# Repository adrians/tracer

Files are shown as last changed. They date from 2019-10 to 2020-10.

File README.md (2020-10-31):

# Electronic tracer

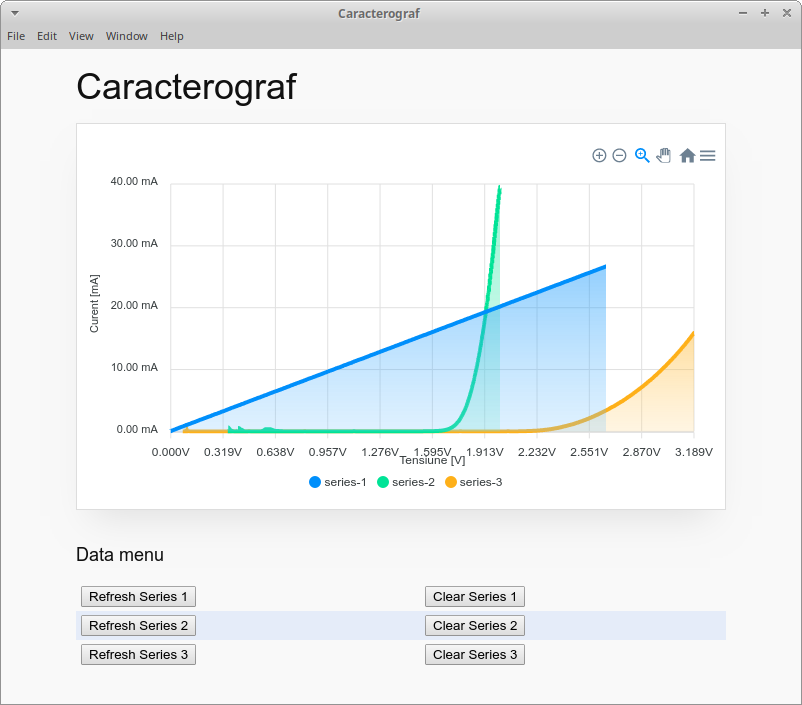
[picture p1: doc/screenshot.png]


## The "driver-v1" folder

* Use it for physical tracer board, version 1.
* Prerequisites: `libudev1` and `g++` installed (`sudo apt-get install libudev1 build-essential`).
* Driver based on Kerry Wong's library (<https://github.com/kerrydwong/MCP2210-Library>).
* To build the driver-application, run `cd driver-v1; make`. It will generate the `tracer` binary, which should be run as root (or with the `setuid` bit set).

## The "driver-mock" folder

* Use it for local testing, without a tracer board. It's a dummy data source.
* Prerequisites: `g++` installed.
* To build it, run `cd driver-mock; make`. It will generate the `tracer` binary.

## The "frontend" directory

* Frontend done using electron.js and apex charts.
* It uses `npm`.
* To build, run `npm install`.
* To run, copy the `tracer` binary (from either `driver-v1` or `driver-mock` directories), and then run `npm start`.
* Tested with node 14.x.

The `driver-v1` requires setuid permissions. See the snippet below.

```bash
cd frontend
cp ../driver-v1/tracer .
sudo chown root tracer
sudo chmod +s tracer
npm start
```

## The "board" directory

* Contains the kicad project used for manufacturing the first iteration of the board.

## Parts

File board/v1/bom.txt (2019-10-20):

22pF, 2buc, C1 C2,      https://ro.farnell.com/vishay/k220j15c0gf53l2/cap-22pf-50v-5-c0g-np0/dp/1141760
10nF, 2buc, C7 C8,      https://ro.farnell.com/multicomp/mc0805y103m500a5-08mm/cap-0-01-f-50v-20-y5v/dp/2309024
1uF, 1buc, C5,          https://ro.farnell.com/multicomp/mcnp35v105m5x11/cap-1-f-35v-20/dp/1236666
2.2uF, 3buc, C3 C4 C6,  https://ro.farnell.com/multicomp/mcksk100m2r2d11s/cap-2-2-f-100v-20/dp/2610808
10uF, 1buc, C9,         https://ro.farnell.com/multicomp/mcgpr16v106m5x11/cap-10-f-16v-20/dp/9451056

led5mm, 1buc, D1,       https://ro.farnell.com/multicomp/mcl053pd/led-5mm-36-hi-red/dp/1581136

100R, 2buc, R1 R2,      https://ro.farnell.com/multicomp/mf25-100r/res-100r-1-250mw-axial-metal-film/dp/9341099
1k, 2buc, R3 R4,        https://ro.farnell.com/multicomp/mcf-0-25w-1k/res-1k-5-250mw-axial-carbon-film/dp/9339051

12MHz xtal, Y1, 1buc,   https://ro.farnell.com/qantek-technology-corporation/qcl12-0000f18b23b/crystal-12mhz-18pf-hc-49us/dp/2508453

terminal 2way 5.08pitch, 2buc, J1 J3,        https://ro.farnell.com/wago/235-402-331-000/terminal-block-wire-to-brd-2pos/dp/1891596

USB B, J2, 1buc,    https://ro.farnell.com/multicomp/usb-b-s-ra/usb-2-0-type-b-receptacle-th/dp/2112373

NPN, Q1, 1buc,      https://ro.farnell.com/stmicroelectronics/tip50/transistor-npn-to-220/dp/1467926
7805, U5, 1buc,     https://ro.farnell.com/stmicroelectronics/l7805cv/ic-v-reg-5-0v-7805-to-220-3/dp/9756078

MCP2210 SOIC, U4, 1buc,     https://ro.farnell.com/microchip/mcp2210-i-so/ic-usb-to-spi-converter-20soic/dp/2078574
MCP4921, U1, 1buc,  https://ro.farnell.com/microchip/mcp4921-e-p/12bit-dac-singl-spi-i-f-mcp4921/dp/1332112
MCP3204, U2, 1buc,  https://ro.farnell.com/microchip/mcp3204-ci-p/ic-12bit-adc-3204-dip14/dp/9758593
MCP6002, U3, 1buc,  https://ro.farnell.com/microchip/mcp6002-i-p/ic-op-amp-1-8v-1mhz-dual-pdip8/dp/1292245
MAX6241, U6, 1buc,  https://ro.farnell.com/maxim-integrated-products/max6241bcpa/voltage-ref-series-4-096v-dip/dp/2511209

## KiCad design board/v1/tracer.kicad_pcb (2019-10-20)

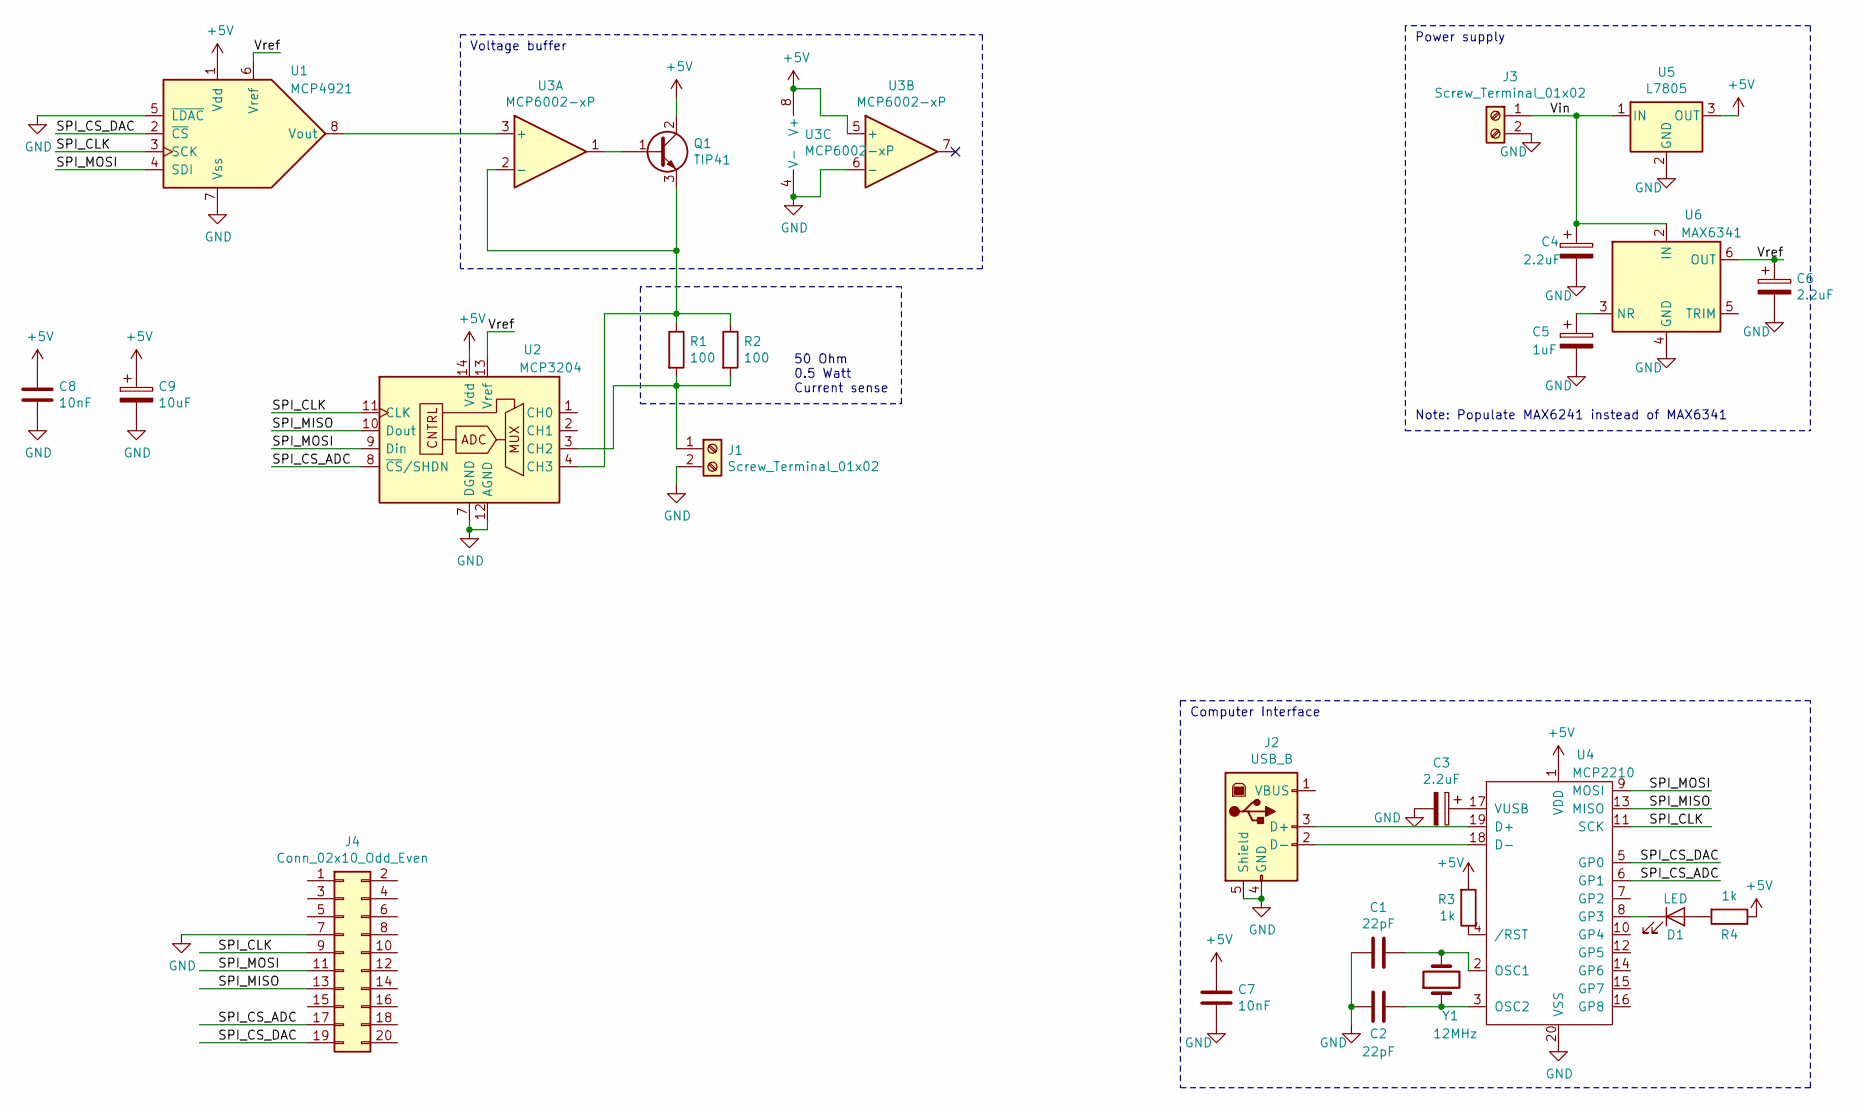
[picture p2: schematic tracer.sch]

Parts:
C1, C2: 22pF; C_Disc_D3.0mm_W1.6mm_P2.50mm
C3, C4, C6: 2.2uF; CP_Radial_D4.0mm_P2.00mm
C5: 1uF; CP_Radial_D4.0mm_P2.00mm
C7, C8: 10nF; C_Disc_D3.0mm_W1.6mm_P2.50mm
C9: 10uF; CP_Radial_D4.0mm_P1.50mm
D1: LED; LED_D5.0mm
J1, J3: Screw_Terminal_01x02; TerminalBlock_Phoenix_MKDS-3-2-5.08_1x02_P5.08mm_Horizontal
J2: USB_B; USB_B_OST_USB-B1HSxx_Horizontal
J4: Conn_02x10_Odd_Even; PinHeader_2x10_P2.54mm_Vertical
Q1: TIP41; TO-220-3_Horizontal_TabDown
R1, R2: 100; R_Axial_DIN0207_L6.3mm_D2.5mm_P7.62mm_Horizontal
R3, R4: 1k; R_Axial_DIN0207_L6.3mm_D2.5mm_P7.62mm_Horizontal
U1: MCP4921; DIP-8_W7.62mm
U2: MCP3204; DIP-14_W7.62mm
U3: MCP6002-xP; DIP-8_W7.62mm
U4: MCP2210; SOIC-20W_7.5x12.8mm_P1.27mm
U5: L7805; TO-220-3_Horizontal_TabDown
U6: MAX6341; DIP-8_W7.62mm
Y1: 12MHz; Crystal_HC50_Vertical

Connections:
+5V: C7.1, C8.1, C9.1, Q1.2 (C), R3.2, R4.1, U1.1 (Vdd), U2.14 (Vdd), U3.5 (+), U3.8 (V+), U4.1 (VDD), U5.3 (OUT)
/SPI_CLK: J4.9, U1.3 (SCK), U2.11 (CLK), U4.11 (SCK)
/SPI_CS_ADC: J4.17, U2.8 (~CS~/SHDN), U4.6 (GP1)
/SPI_CS_DAC: J4.19, U1.2 (~CS), U4.5 (GP0)
/SPI_MISO: J4.13, U2.10 (Dout), U4.13 (MISO)
/SPI_MOSI: J4.11, U1.4 (SDI), U2.9 (Din), U4.9 (MOSI)
/Vin: C4.1, J3.1, U5.1 (IN), U6.2 (IN)
/Vref: C6.1, U1.6 (Vref), U2.13 (Vref), U6.6 (OUT)
GND: C1.2, C2.1, C3.2, C4.2, C5.2, C6.2, C7.2, C8.2, C9.2, J1.2, J2.4 (GND), J2.5 (Shield), J3.2, J4.7, U1.5 (~LDAC), U1.7 (Vss), U2.7 (DGND), U2.12 (AGND), U3.4 (V-), U3.6 (-), U4.20 (VSS), U5.2 (GND), U6.4 (GND)
unnamed: C1.1, U4.2 (OSC1), Y1.2
unnamed: C2.2, U4.3 (OSC2), Y1.1
unnamed: C3.1, U4.17 (VUSB)
unnamed: C5.1, U6.3 (NR)
unnamed: D1.1 (K), U4.8 (GP3)
unnamed: D1.2 (A), R4.2
unnamed: J1.1, R1.2, R2.2, U2.3 (CH2)
unnamed: J2.2 (D-), U4.18 (D-)
unnamed: J2.3 (D+), U4.19 (D+)
unnamed: Q1.1 (B), U3.1
unnamed: Q1.3 (E), R1.1, R2.1, U2.4 (CH3), U3.2 (-)
unnamed: R3.1, U4.4 (/RST)
unnamed: U1.8 (Vout), U3.3 (+)

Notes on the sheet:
Power supply
Note: Populate MAX6241 instead of MAX6341
Computer Interface
50 Ohm 0.5 Watt Current sense
Voltage buffer

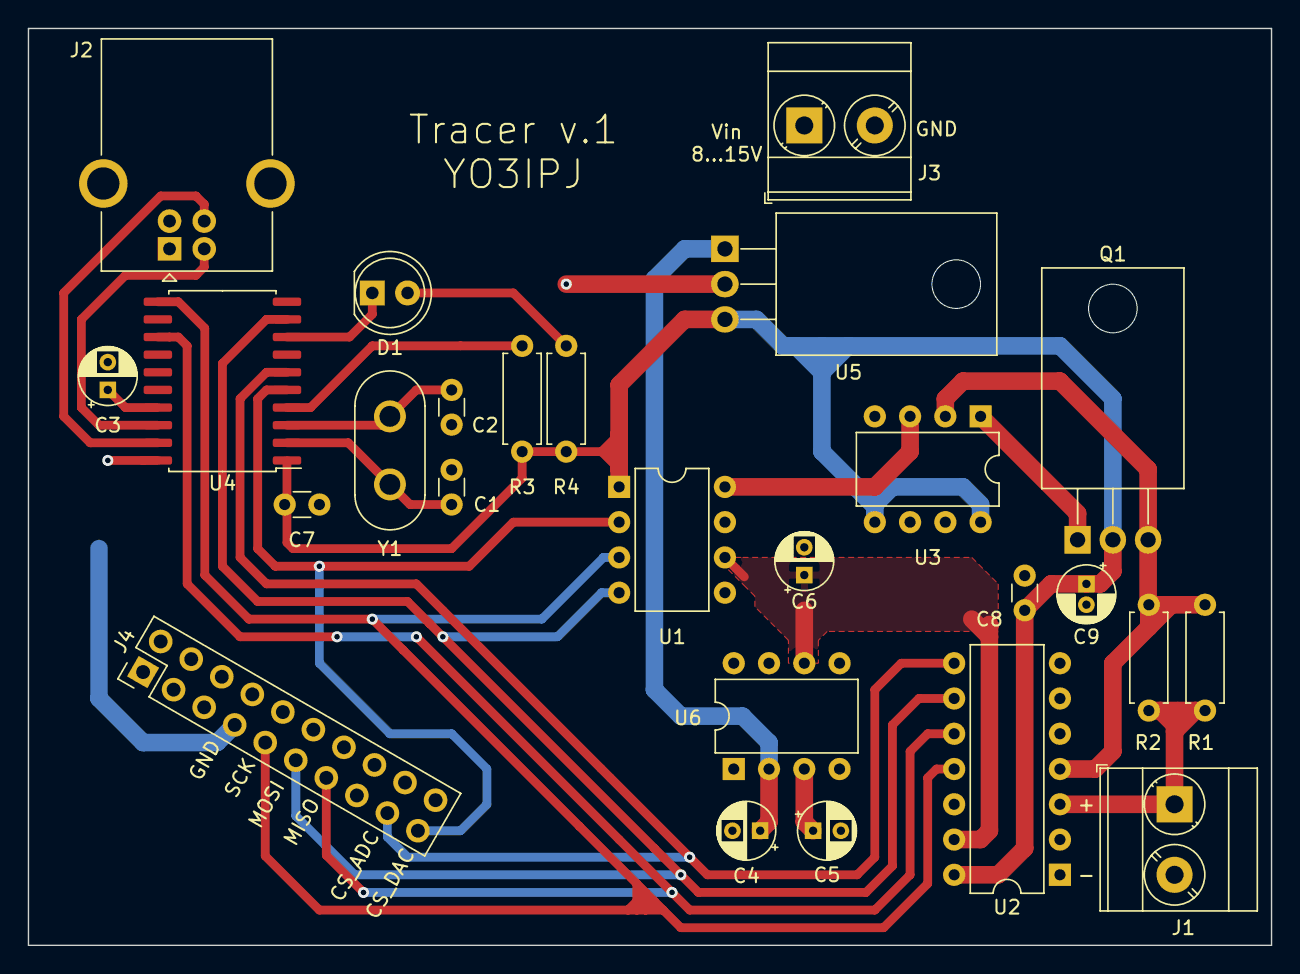
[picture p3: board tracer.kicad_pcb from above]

Board: 2 copper layers, 89.5 x 66.0 mm, 26 parts (0 on the bottom side), 22 nets.

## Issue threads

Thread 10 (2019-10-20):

Next-gen board

adrians, 2019-10-20:
Must-have:
[ ] mounting holes
[ ] input voltage protection
[ ] reverse supply voltage protection
[ ] cheaper voltage reference
[ ] DUT discharge resistor (v1 can "source" current but cannot lower the DUT voltage by itself)

Nice-to-have:
[ ] on-board SPI chip - provide fast sampling and buffer data to RAM - allow RC characteristics to be plotted
[ ] transistor-tracer (add another channel)

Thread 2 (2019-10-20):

DEB build

adrians, 2019-10-20:
Currently, the application is delivered as a "zip" file which is uncompressed manually. This procedure does not preserve the "setuid" bit).

Packaging it as a "deb" would solve a few problems (setting the "setuid" bit, adding the application in path, adding it to the GUI menus).

Needed: script that makes a build and generates the "deb" package.

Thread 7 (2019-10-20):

Driver error handling

adrians, 2019-10-20:
Implement better error handling.

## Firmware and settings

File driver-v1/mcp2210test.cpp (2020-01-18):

/**
 *    Copyright 2012, Kerry D. Wong
 * 
 *      http://www.kerrywong.com
 *
 *  Licensed under the Apache License, Version 2.0 (the "License");
 *  you may not use this file except in compliance with the License.
 *  You may obtain a copy of the License at
 *
 *      http://www.apache.org/licenses/LICENSE-2.0
 *
 *  Unless required by applicable law or agreed to in writing, software
 *  distributed under the License is distributed on an "AS IS" BASIS,
 *  WITHOUT WARRANTIES OR CONDITIONS OF ANY KIND, either express or implied.
 *  See the License for the specific language governing permissions and
 *  limitations under the License.
 */

#include "mcp2210.h"

using namespace std;

static SPITransferSettingsDef def;

void initTracer(hid_device* handle) {
    ChipSettingsDef chipDef;

    //set GPIO pins to be CS
    chipDef = GetChipSettings(handle);

    for (int i = 0; i < 9; i++) {
        if (i == 3) {
        	chipDef.GP[i].PinDesignation = GP_PIN_DESIGNATION_DEDICATED;
        	chipDef.GP[i].GPIODirection = GPIO_DIRECTION_OUTPUT;
        	chipDef.GP[i].GPIOOutput = 1;
        } else {
		chipDef.GP[i].PinDesignation = GP_PIN_DESIGNATION_CS;
        	chipDef.GP[i].GPIODirection = GPIO_DIRECTION_OUTPUT;
        	chipDef.GP[i].GPIOOutput = 1;
	}
    }

    int r = SetChipSettings(handle, chipDef);
    if (r != 0) {
        printf("Error setting SPI parameters.\n");
        return;
    }
    def = GetSPITransferSettings(handle);
}

void SetMCP4921(hid_device* handle, uint16_t input) {
    //chip select is GP0
    def.ActiveChipSelectValue = 0xfffe;
    def.IdleChipSelectValue = 0xffff;
    def.BitRate = 50000l;
    def.BytesPerSPITransfer = 2;

    int r = SetSPITransferSettings(handle, def);

    if (r != 0) {
        printf("Error setting SPI parameters.\n");
        return;
    }
    
    byte spiCmdBuffer[2];
    spiCmdBuffer[0] = (0x30) | ((input >> 8) & 0x0F);
    spiCmdBuffer[1] = (input & 0xFF);
    SPIDataTransferStatusDef def1 = SPISendReceive(handle, spiCmdBuffer, 2);
}

uint16_t GetMCP3204(hid_device* handle, uint8_t channel) {
    //chip select is GP0
    def.ActiveChipSelectValue = 0xfffd;
    def.IdleChipSelectValue = 0xffff;
    def.BitRate = 50000l;
    def.BytesPerSPITransfer = 3;

    int r = SetSPITransferSettings(handle, def);

    if (r != 0) {
        printf("Error setting SPI parameters.\n");
        return 0;
    }
    
    byte spiCmdBuffer[3];
    spiCmdBuffer[0] = (1<<6) | (1<<5) | (channel << 2);
    spiCmdBuffer[1] = 0x00;
    spiCmdBuffer[2] = 0x00;
    SPIDataTransferStatusDef def1 = SPISendReceive(handle, spiCmdBuffer, 2);

    return def1.DataReceived[1]*16 + (def1.DataReceived[0]/16);
}

int main(int argc, char** argv) {
    hid_device *handle;
    handle = InitMCP2210();
    if (handle == 0) {
        printf("ERROR opening device. Try using sudo.\n");
        exit(-1);
    }

    initTracer(handle);
    printf("{\"data\": [\n");
    for (int i = 0; i < 4000; i = i+10){
        SetMCP4921(handle, i);
	uint16_t dut = GetMCP3204(handle, 2);
	uint16_t supply = GetMCP3204(handle, 3);

	if(i != 0){
		printf(",");
	}
	printf("[%d.%03d, %d.%03d]\n",
			dut/1000,
			dut%1000,
			((supply - dut) >= 0) ? ((supply - dut)*1000/50)/1000 : 0,
			((supply - dut) >= 0) ? (((supply - dut)*1000/50)%1000) : 0
	);
    }
    SetMCP4921(handle, 0);
    printf("]}\n");
    ReleaseMCP2210(handle);

    return 0;
}

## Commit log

2020-01-12 driver: document prerequisites
2020-02-15 driver: add dummy data source, fix #12
    [mcp2210test.cpp]
